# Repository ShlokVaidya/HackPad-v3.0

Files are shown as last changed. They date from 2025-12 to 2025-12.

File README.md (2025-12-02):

# HackPad v3.0

### Schematic
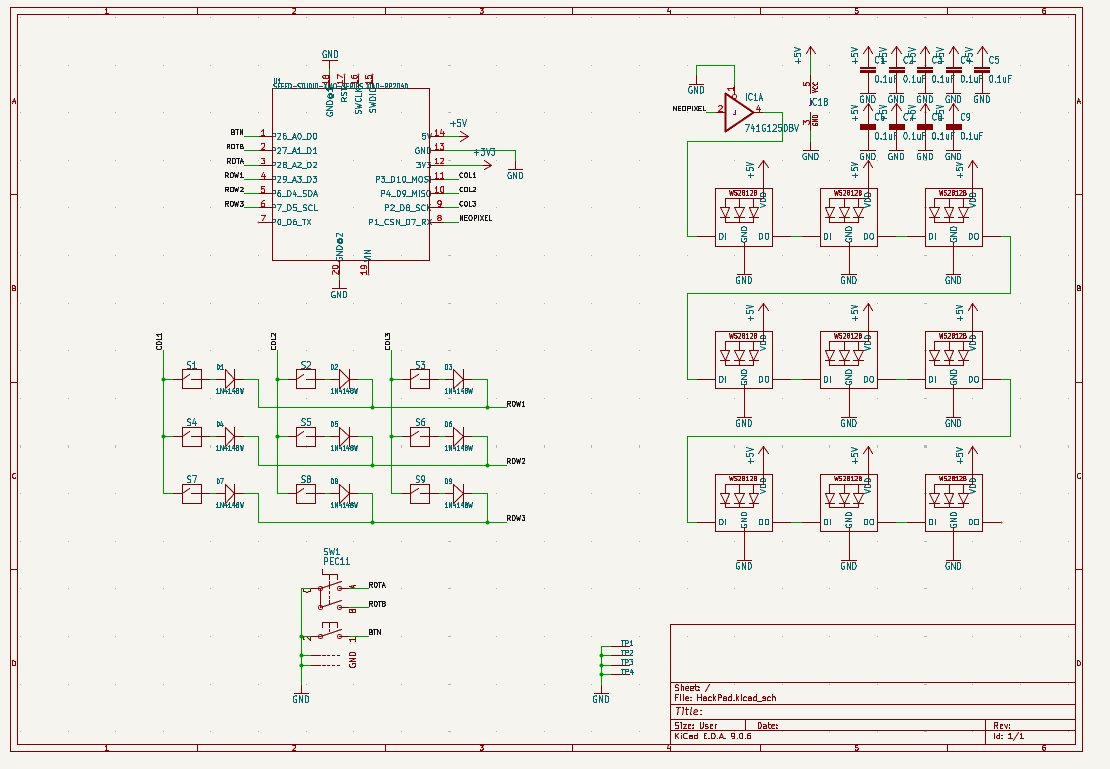
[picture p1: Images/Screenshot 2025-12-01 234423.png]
Schematic


### PCB
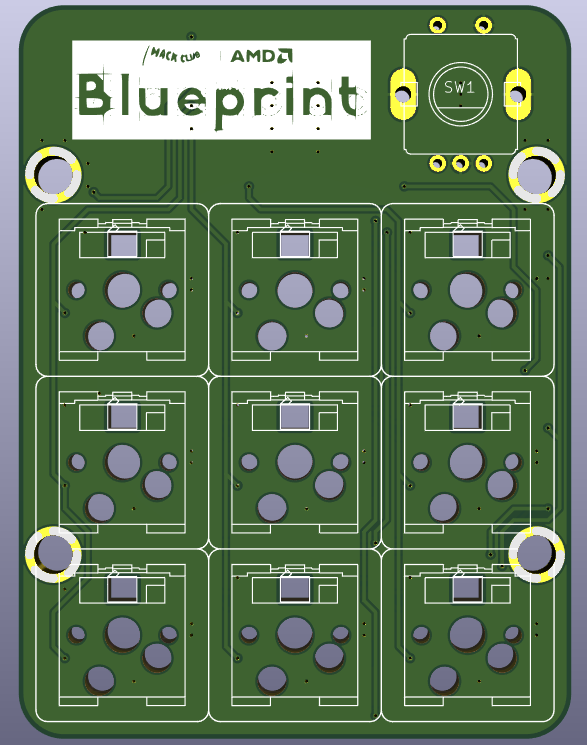
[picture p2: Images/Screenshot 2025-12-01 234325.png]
PCB


### 3D
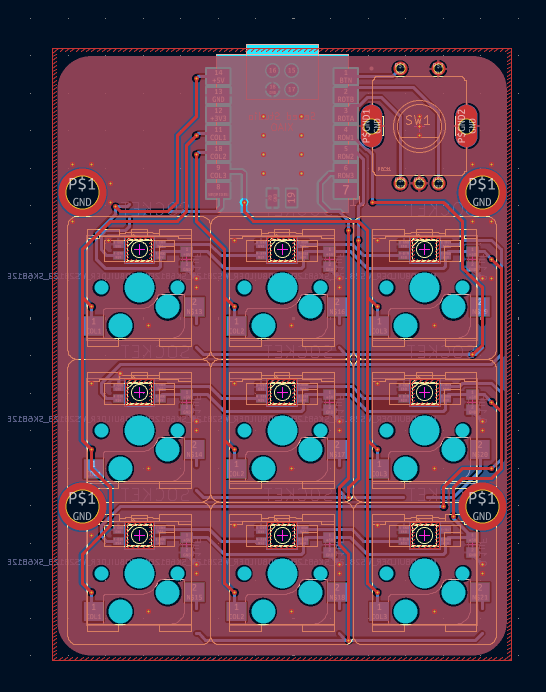
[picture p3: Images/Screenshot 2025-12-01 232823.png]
3d


### 3D case
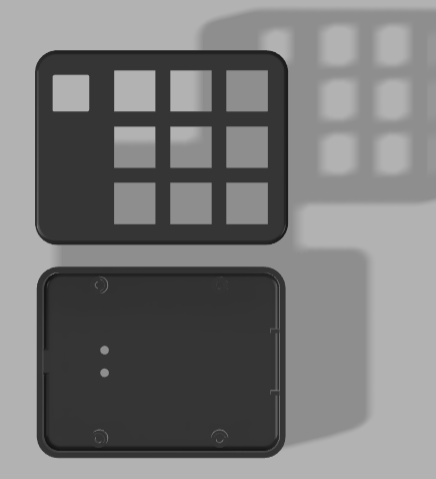
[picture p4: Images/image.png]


### Final Product
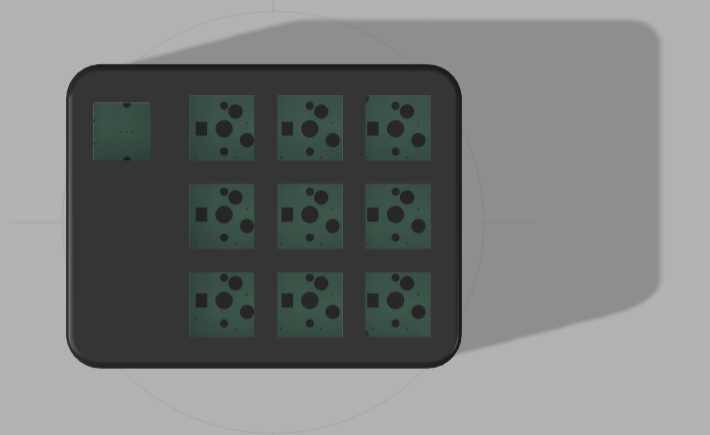
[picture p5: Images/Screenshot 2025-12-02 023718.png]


### bom.csv


bom

## Features

- Uses Seeed XIAO RP2040, a small form factor board based on the Raspberry Pi RP2040 microcontroller.
- Supports MicroPython and CircuitPython.
- Kailh hot-swappable sockets compatible with 3-pin and 5-pin MX switches.
- Rotary quadrature encoder with push button.
- SK6812 reverse-mounted addressable RGB LEDs to backlight each key.
- Power and communication through a USB-C type port.
- Compatible with KMK keyboard firmware.
- Compatible with Windows, macOS, and Linux operating systems.
- Dimensions: 61mm x 81mm x 31mm (without case), 66mm x 86mm x 35mm (with 3D-printed case).

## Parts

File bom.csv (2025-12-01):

Designator | Footprint | Quantity | Value | LCSC Part #
C1, C2, C3, C4, C5, C6, C7, C8, C9 | C0805K_334 | 9 | 0.1uF
LED1, LED2, LED3, LED4, LED5, LED6, LED7, LED8, LED9 | MICROBUILDER_NEO3535_REVERSE | 9 | MICROBUILDER_WS2812B_SK6812E
S1, S2, S3, S4, S5, S6, S7, S8, S9 | ADAFRUIT_ELECTROMECH_KAILH_SOCKET | 9 | SOCKET
SW1 | ADAFRUIT_ELECTROMECH_PEC11+SWITCH | 1 | PEC11
TP1, TP2, TP3, TP4 | SMT_NUT_3MM | 4 | SEWTAP_SMTNUTM3
U1 | SEEED-STUDIO-XIAO-SERIES_XIAO-SAMD21_RP2040-MODULE14P-2.54-21X17.8MM | 1 | SEEED-STUDIO-XIAO-SERIES_XIAO-RP2040

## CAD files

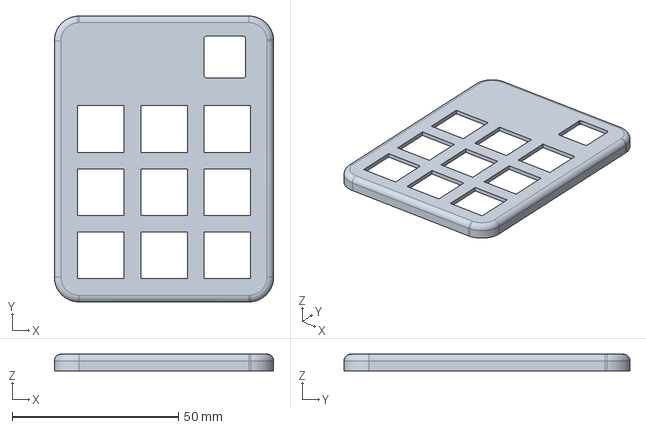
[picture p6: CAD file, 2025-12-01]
CAD/HackPadCover.step
66.0 x 86.0 x 5.00 mm

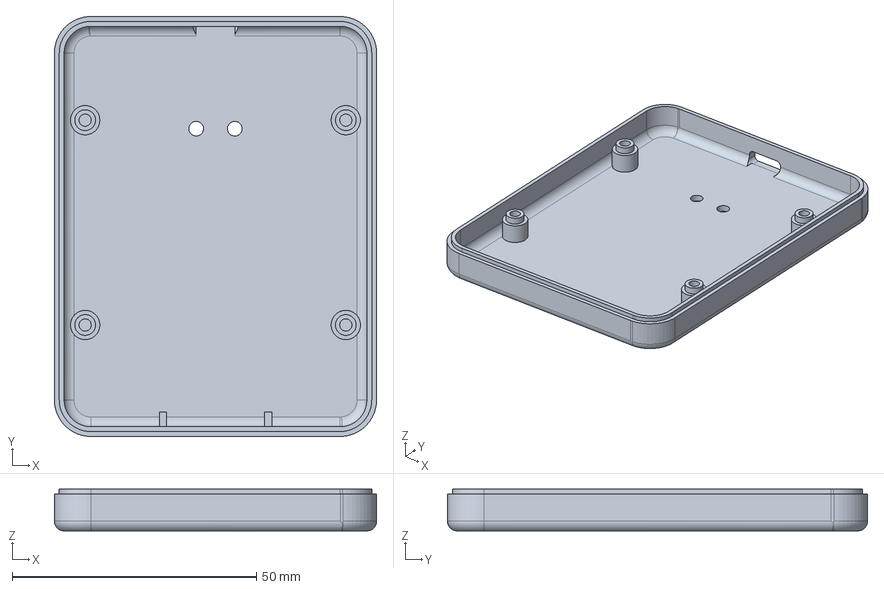
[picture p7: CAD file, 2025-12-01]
CAD/HackPadBase.step
66.0 x 86.0 x 8.56 mm

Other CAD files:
CAD/HackPadBase.stl
CAD/HackPadCover.stl

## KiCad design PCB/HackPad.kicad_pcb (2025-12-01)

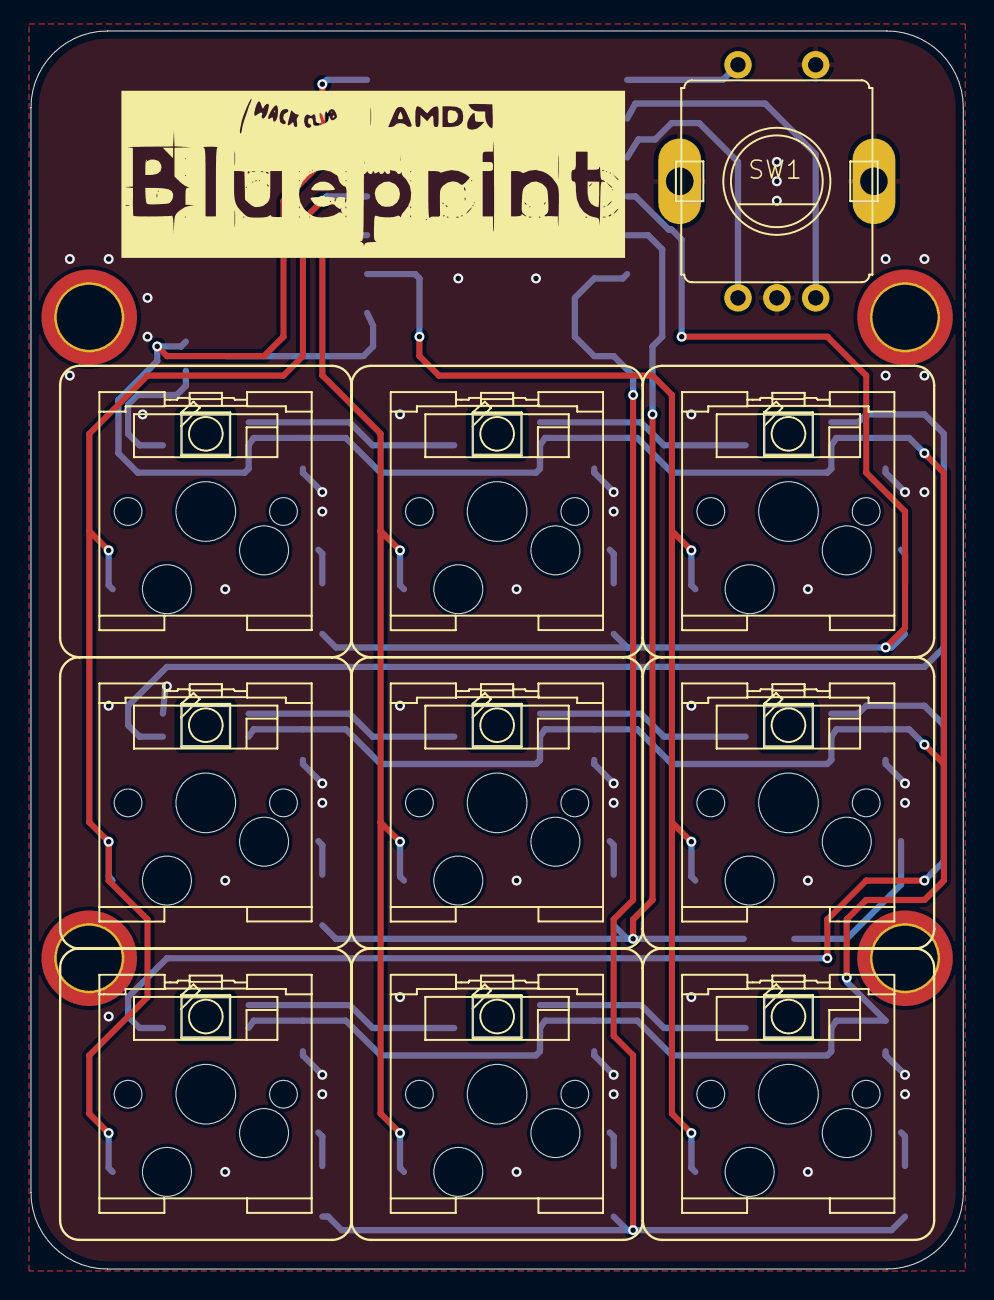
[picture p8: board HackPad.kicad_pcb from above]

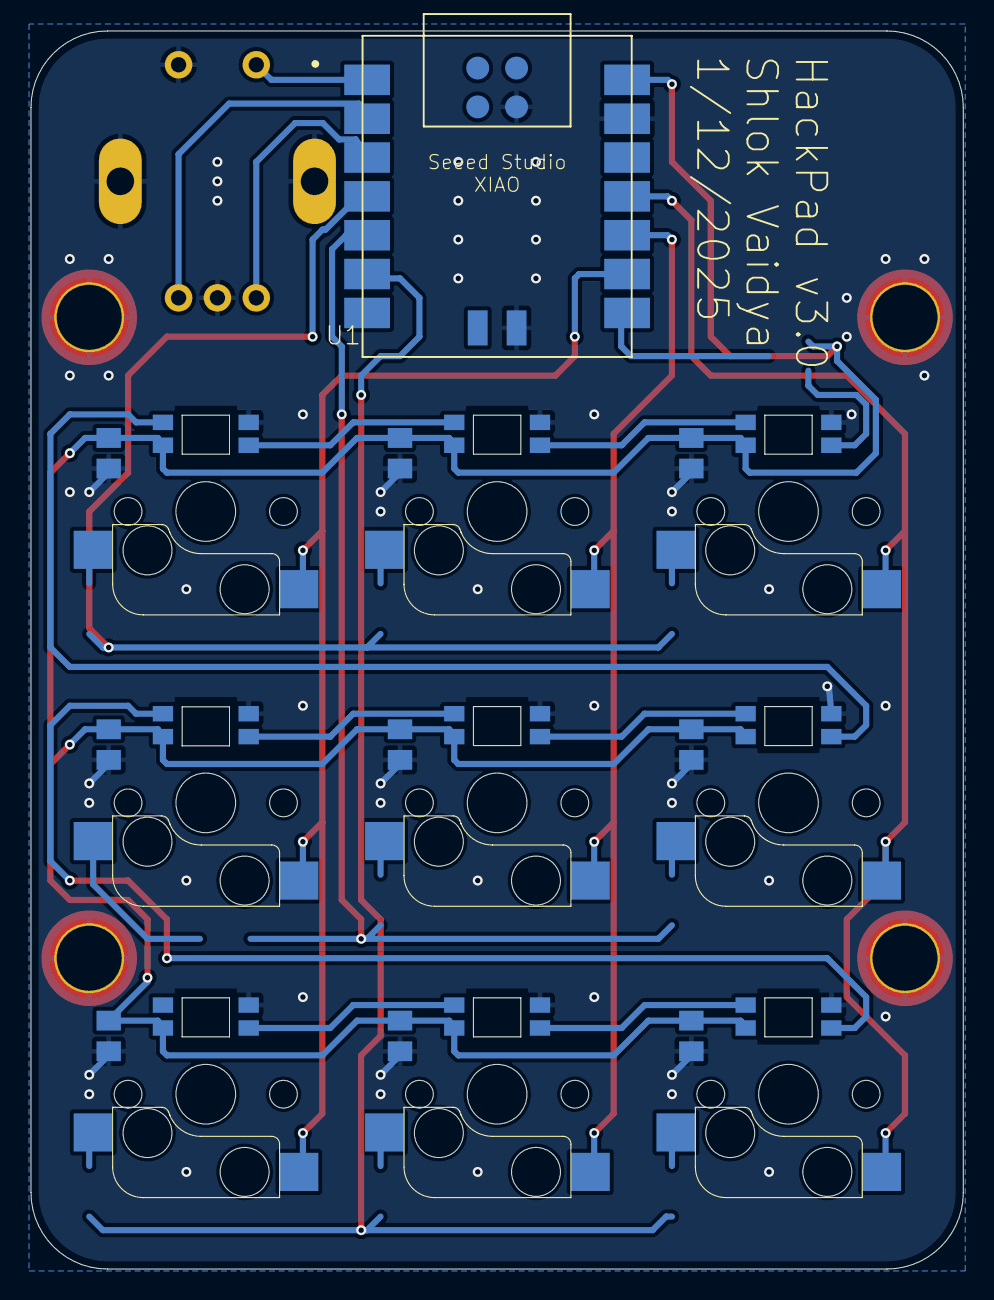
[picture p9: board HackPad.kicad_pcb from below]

Board: 2 copper layers, 61.0 x 81.0 mm, 33 parts (10 on the bottom side), 16 nets.

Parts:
C1, C2, C3, C4, C5, C6, C7, C8, C9: 0.1uF; C0805K_334
LED1, LED2, LED3, LED4, LED5, LED6, LED7, LED8, LED9: MICROBUILDER_WS2812B_SK6812E; MICROBUILDER_NEO3535_REVERSE
S1, S2, S3, S4, S5, S6, S7, S8, S9: SOCKET; ADAFRUIT_ELECTROMECH_KAILH_SOCKET
SW1: PEC11; ADAFRUIT_ELECTROMECH_PEC11+SWITCH
TP1, TP2, TP3, TP4: SEWTAP_SMTNUTM3; SMT_NUT_3MM
U1: SEEED-STUDIO-XIAO-SERIES_XIAO-RP2040; SEEED-STUDIO-XIAO-SERIES_XIAO-SAMD21_RP2040-MODULE14P-2.54-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

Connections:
+5V: C1.1, C2.1, C3.1, C4.1, C5.1, C6.1, C7.1, C8.1, C9.1, LED1.1-VDD, LED2.1-VDD, LED3.1-VDD, LED4.1-VDD, LED5.1-VDD, LED6.1-VDD, LED7.1-VDD, LED8.1-VDD, LED9.1-VDD, U1.14
BTN: SW1.P$1, U1.1
COL1: S1.1, S4.1, S7.1, U1.11
COL2: S2.1, S5.1, S8.1, U1.10
COL3: S3.1, S6.1, S9.1, U1.9
GND: C1.2, C2.2, C3.2, C4.2, C5.2, C6.2, C7.2, C8.2, C9.2, LED1.3-GND, LED2.3-GND, LED3.3-GND, LED4.3-GND, LED5.3-GND, LED6.3-GND, LED7.3-GND, LED8.3-GND, LED9.3-GND, SW1.P$2, SW1.P$C, SW1.P$GND1, SW1.P$GND2, TP1.P$1, TP2.P$1, TP3.P$1, TP4.P$1, U1.13, U1.18, U1.20
unnamed: LED8.2-DOUT, LED9.4-DIN
unnamed: LED7.2-DOUT, LED8.4-DIN
unnamed: LED5.2-DOUT, LED6.4-DIN
unnamed: LED6.2-DOUT, LED7.4-DIN
unnamed: LED4.2-DOUT, LED5.4-DIN
unnamed: LED3.2-DOUT, LED4.4-DIN
unnamed: LED1.2-DOUT, LED2.4-DIN
unnamed: LED2.2-DOUT, LED3.4-DIN
ROTA: SW1.P$A, U1.3
ROTB: SW1.P$B, U1.2

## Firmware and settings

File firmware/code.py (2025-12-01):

import board
from kmk.kmk_keyboard import KMKKeyboard
from kmk.keys import KC
from kmk.scanners import DiodeOrientation
from kmk.extensions.RGB import RGB, AnimationModes
from kmk.extensions.media_keys import MediaKeys
from kmk.modules.encoder import EncoderHandler

# Pinout
COL1 = board.D10
COL2 = board.D9
COL3 = board.D8
ROW1 = board.D3
ROW2 = board.D4
ROW3 = board.D5
PUSHBUTTON = board.D0
ROTA = board.D2
ROTB = board.D1
NEOPIXEL = board.D7

keyboard = KMKKeyboard()

# Basic matrix settings
keyboard.col_pins = (COL1, COL2, COL3)
keyboard.row_pins = (ROW1, ROW2, ROW3)
keyboard.diode_orientation = DiodeOrientation.COL2ROW

# RGB LEDs settings
rgb_ext = RGB( 
    pixel_pin = NEOPIXEL,
    num_pixels = 9,
    hue_default = 100,
    sat_default = 255,
    val_default = 15,
    val_limit = 25,
    animation_speed = 1,
    animation_mode=AnimationModes.RAINBOW,
    refresh_rate = 30,
)
keyboard.extensions.append(rgb_ext)
keyboard.extensions.append(MediaKeys())

# Encoder settings
encoder_handler = EncoderHandler()
keyboard.modules.append(encoder_handler)
encoder_handler.pins = ((ROTA, ROTB, PUSHBUTTON, False),)
encoder_handler.map = (((KC.VOLD, KC.VOLU, KC.MUTE),),)

# Keymap
keyboard.keymap = [
    [KC.LCTRL(KC.LSHIFT(KC.TAB)), KC.LCTRL(KC.M), KC.LCTRL(KC.TAB),
     KC.MEDIA_PREV_TRACK, KC.MEDIA_PLAY_PAUSE, KC.MEDIA_NEXT_TRACK,
     KC.LCTRL(KC.C), KC.LCTRL(KC.V), KC.LGUI(KC.SPACE),
    ]
]

if __name__ == '__main__':
    keyboard.go()

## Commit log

2025-12-01 HackPad v3.0
    [HackPad.kicad_pcb, HackPad.kicad_sch, HackPadBase.step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]
2025-12-02 Added bom.csv
    [bom.csv]
2025-12-02 Add SVG image for bom in README
